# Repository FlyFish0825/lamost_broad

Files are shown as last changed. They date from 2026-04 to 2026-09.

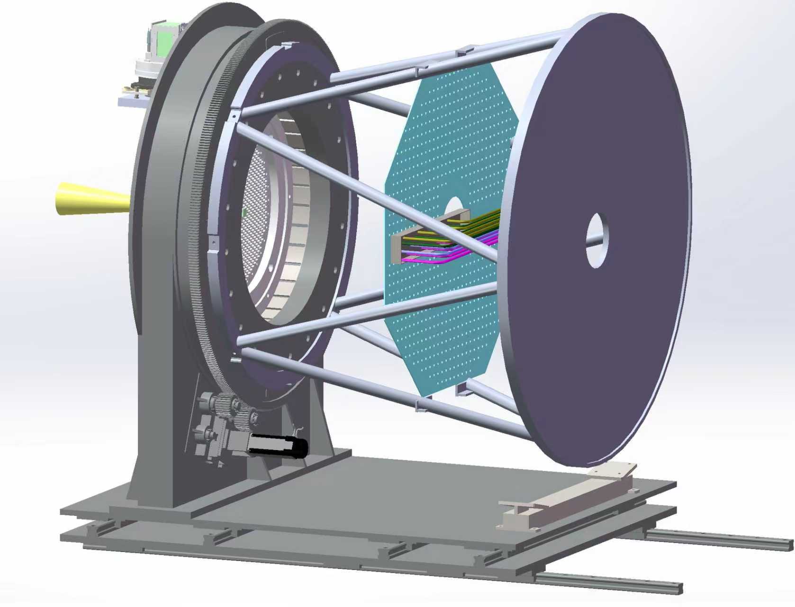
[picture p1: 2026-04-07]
just外接板/picture/微信图片_20260402115243_79_106.jpg

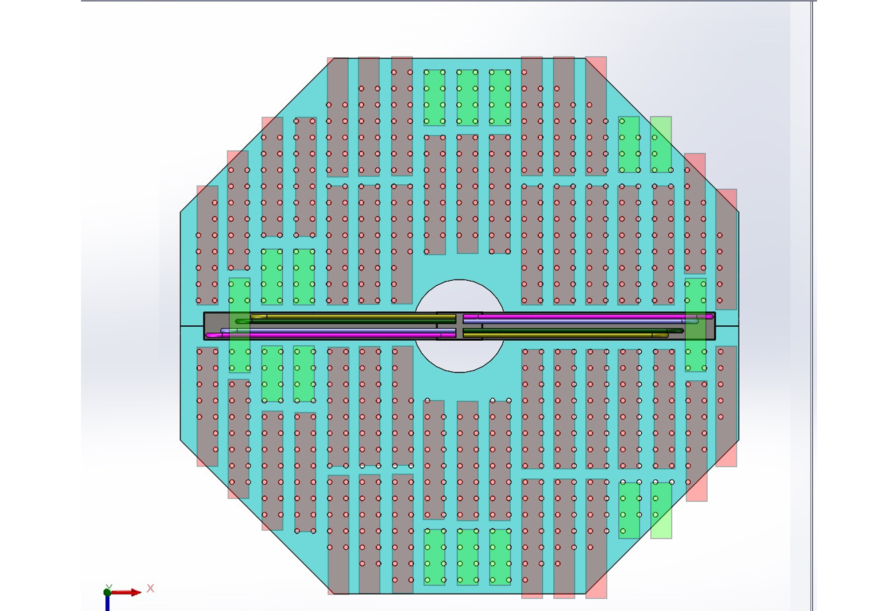
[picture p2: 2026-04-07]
just外接板/picture/示意图4.jpg

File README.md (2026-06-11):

# LAMOST 外接板（Broad Board）

LAMOST（Large Sky Area Multi-Object Fiber Spectroscopic Telescope）光谱巡天望远镜外接板项目。本项目包含一块约 **1.3 米**的大尺寸基板（机械背板），以及安装在其上的 **56 块小单元 PCB**。每块小单元 PCB 搭载一片 STM32F302 MCU，各 PCB 之间通过基板上的 CAN 总线互联通信，用于光纤光谱仪的信号中继与分配。

## 项目概览

| 类别 | 说明 |
|---|---|
| **主控芯片** | STM32F302x8（Cortex-M4, 72MHz），每块小单元 PCB 一片 |
| **通信方式** | CAN 2.0, 250kbps，CAN 总线绘制在基板上，56 节点多主网络 |
| **晶振** | 24MHz 外部晶振 |
| **基板尺寸** | ≈1.3m，中间方形倒角，走线孔直径 50mm，中间孔 150mm |
| **小单元 PCB** | 共 56 块，每块搭载 STM32F302 + CAN 收发器，16 通道输出 |
| **PCB 层数** | 2 层板（小单元 PCB） |
| **设计工具** | 立创EDA / EasyEDA (PCB), SolidWorks (3D 结构) |
| **开发周期** | 2026.03 — 至今 |
| **作者** | dushiyu ([FlyFish0825](https://github.com/FlyFish0825)) |

## 系统架构

```
┌──────────────────────────────────────────────────────────────────┐
│                      基板（外接板基板）≈1.3m                        │
│                                                                  │
│   ┌──────────┐  ┌──────────┐  ┌──────────┐       ┌──────────┐   │
│   │  PCB #1  │  │  PCB #2  │  │  PCB #3  │  ...  │  PCB #56 │   │
│   │ STM32F302│  │ STM32F302│  │ STM32F302│       │ STM32F302│   │
│   │ CAN收发器│  │ CAN收发器│  │ CAN收发器│       │ CAN收发器│   │
│   │ 16通道   │  │ 16通道   │  │ 16通道   │       │ 16通道   │   │
│   └────┬─────┘  └────┬─────┘  └────┬─────┘       └────┬─────┘   │
│        └──────────────┴─────────────┴── CAN 总线 ────┘          │
│                         基板上走线                                │
│   ┌──────────────────────────────────────────────────────────┐   │
│   │                    电源总线（基板上走线）                    │   │
│   └──────────────────────────────────────────────────────────┘   │
│                                                                  │
│   走线孔 Φ50mm × N         中心孔 Φ150mm                         │
└──────────────────────────────────────────────────────────────────┘
```

- **基板（外接板基板）**：大型机械背板，上面绘制 CAN 总线和电源线，开有走线孔和中心孔，56 块小单元 PCB 安装固定其上
- **小单元 PCB**：共 56 块，每块搭载一片 STM32F302 MCU 和 CAN 收发器，16 通道输出。各 PCB 通过基板上的 CAN 总线互联，形成 56 节点多主 CAN 网络。其中一块作为主节点（主节点布局已调整优化）
- **CAN 总线**：在基板上走线，连接所有 56 块 PCB，总线两端含开关控制的 120Ω 终端电阻

## 目录结构

```
lamost_broad/
├── Canvas/                           # PCB 接口映射可视化工具
│   ├── canvas.html                   # HTML Canvas 交互式编辑器（707行）
│   ├── pcb_c_array.txt               # 52块PCB的C数组映射数据（待更新至56块）
│   └── pcb_mapping_*.json            # 接口映射关系 JSON 数据
│
├── just外接板/                        # 基板及 PCB SolidWorks 3D 模型、汇报资源
│   ├── picture/                      # 示意图、实物照片、PSD 设计稿
│   │   ├── 主节点布局.png/psd        # 主节点布局图
│   │   ├── 正视图.png / 正视图布线.psd # 基板正视图及布线图
│   │   ├── 示意图.jpg / 示意图2/4.jpg # 多种视角示意图
│   │   ├── 示意图横置.jpg            # 横置示意图
│   │   ├── 数目.png                  # PCB 数量统计图
│   │   ├── 对照.psd                  # 对照设计稿
│   │   └── QQ*/微信图片_*.jpg        # 实物及参考照片
│   ├── ppt/                          # 阶段性汇报 PPT（5个版本）
│   │   ├── 0402.pptx                 # 4月2日汇报
│   │   ├── 0409.pptx                 # 4月9日汇报
│   │   ├── 0413.pptx                 # 4月13日汇报
│   │   ├── 0423.pptx                 # 4月23日汇报
│   │   └── 0429.pptx                 # 4月29日汇报
│   ├── 外接板基板.SLDPRT / .STEP     # 基板（大型机械背板）3D 模型
│   ├── 基板1.SLDPRT / 基板2.SLDPRT / .STL  # 基板各版本
│   ├── 分块插线板_16.STEP            # 16通道分块插线板（小单元PCB模型）
│   ├── 分块插线板_16接头间距加大.STEP # 加大接头间距版本
│   ├── 外接板.SLDPRT / 外接板pcb.SLDPRT # 外接板及PCB装配
│   ├── 布线.SLDPRT / .STL            # 基板上的布线 3D 模型
│   ├── 接口.step / 接口示意/         # 接口模型及示意工程
│   └── 示意图.psd                    # 总体示意图设计稿
│
├── lamost_broad_MCU/                 # STM32F302 嵌入式固件工程（烧录至每块小单元 PCB）
│   ├── Core/
│   │   ├── Inc/                      # 头文件（can.h, gpio.h, tim.h, usart.h, main.h 等）
│   │   ├── Src/                      # 源文件（main.c, can.c, tim.c, gpio.c, dma.c 等）
│   │   └── pcb_broad/                # PCB 端口映射数组（just_led.c/h）
│   ├── Drivers/                      # STM32 HAL 库驱动
│   ├── CMakeLists.txt                # CMake 构建配置
│   ├── CMakePresets.json             # CMake 预设
│   ├── lamost_broad_MCU.ioc          # STM32CubeMX 配置文件
│   ├── startup_stm32f302x8.s         # 启动汇编文件
│   ├── STM32F302XX_FLASH.ld          # 链接脚本
│   └── build/                        # 构建输出
│
├── pcb_3d_model/                     # PCB 3D 装配模型
│   ├── 3D_PCB2_2026-04-02.SLDASM     # SolidWorks 装配体
│   └── 3D_PCB2_2026-04-02.step       # STEP 通用格式
│
├── 外接板20260402.eprj               # 最新版基板工程文件（立创EDA）
├── 外接板20260112_DXF/               # 基板 DXF 机械图 / PDF 导出
│   ├── DXF_PCB2_2026-01-12_AutoCAD2007.dxf
│   └── PCB_PCB2_2026-01-12.pdf
├── 小单元原理图设计+PCB.zip           # 小单元 PCB 参考设计（原理图+PCB+说明文档）
├── 外接板20260*.eprj                 # 各历史版本基板工程文件
├── 外接板*_backup/                   # 各版本自动备份归档
├── debug.log                         # 调试日志
└── README.md                         # 本文件
```

## 硬件架构详解

### 基板（外接板基板）—— 机械背板

基板是一块约 **1.3 米**的大型机械背板，用于承载 56 块小单元 PCB 并提供互联走线：

- **尺寸**：约 1.3m，中间为方形倒角设计
- **材质**：金属/绝缘基材
- **走线孔**：多个直径 Φ50mm 的走线孔，用于线缆穿绕
- **中心孔**：中间开 Φ150mm 大直径孔
- **对位孔**：含中心对位圆柱孔，用于 PCB 安装定位
- **挖空区域**：特定区域镂空/挖空处理
- **基板布线**：基板上绘制 CAN 总线（统一在右侧走线）和电源总线，连接各 PCB
- **电源接口**：电源接口位于基板背面

基板 3D 模型文件：
- `just外接板/外接板基板.SLDPRT` / `外接板基板.STEP` — SolidWorks 零件及通用格式
- `just外接板/基板2.STL` — 3D 打印格式（约 31MB）
- `just外接板/布线.SLDPRT` / `布线.STL` — 基板布线模型（约 19MB）

### 小单元 PCB —— 56 块（搭载 STM32）

每块小单元 PCB 是一款独立的两层电路板，搭载完整的 MCU 系统，安装在基板之上：

| 参数 | 说明 |
|---|---|
| **数量** | 共 56 块 |
| **MCU** | STM32F302x8（Cortex-M4, 72MHz），每块一片 |
| **通道数** | 每块 16 个通道/端口 |
| **总端口** | 56 × 16 = 896 个 |
| **层数** | 2 层板 |
| **晶振** | 24MHz 外部晶振 |
| **CAN 收发器** | 外接 CAN 收发芯片，接入基板上的 CAN 总线 |
| **电源方案** | 5V → 3.3V，功率电感降压，钽电容滤波 |
| **终端电阻** | 120Ω CAN 终端匹配电阻，开关控制（位于总线两端节点） |
| **LED 指示** | PWM 控制 LED（10% 占空比起步） |
| **调试接口** | SWD 调试/下载接口 |
| **复位** | Boot0 复位电路 |
| **网络拓扑** | 56 节点多主 CAN 网络，其中一块为主节点 |

> 所有 56 块 PCB 运行同一份固件（`lamost_broad_MCU/`），通过 CAN 总线协议中的节点 ID 区分角色。主节点负责协调调度，各从节点响应指令。

小单元 PCB 参考设计（`小单元原理图设计+PCB.zip`）包含：
- 原理图（PDF）
- PCB 布局图（PDF + 仿真顶层/底层图）
- SMT 3D 渲染图（含标注）
- 实物照片（顶层/底层）
- 主体尺寸图
- 设计说明文档（docx）

### 分块插线板

用于连接各小单元 PCB 的接口模块（16 通道），3D 模型文件：
- `分块插线板_16.STEP` — 标准间距版本
- `分块插线板_16接头间距加大.STEP` — 加大接头间距版本

## 固件功能

固件工程 `lamost_broad_MCU/` 基于 STM32CubeMX + HAL 库，使用 CMake 构建，烧录至每一块小单元 PCB 上运行。

### 主要功能模块

| 模块 | 说明 |
|---|---|
| **CAN 通信** | FIFO0 中断收发，250kbps，Filter 全部接收模式，56 节点多主网络 |
| **LED 控制** | PWM 调光（10% 占空比起步），`just_led.c/h` 实现 |
| **DMA** | 数据搬移，用于 CAN 数据高效传输 |
| **UART** | printf 重定向，调试打印输出 |
| **TIM** | 定时器用于 PWM 生成和时序控制 |
| **GPIO** | 通用 IO 控制，CAN 引脚复用配置 |
| **中断** | CAN FIFO0 中断接收，接收值存储与处理 |
| **端口映射** | `pcb_1_map[16]` 等数组定义基板孔位到 PCB 端口的映射关系 |

### 关键引脚映射

| 功能 | 引脚 | 说明 |
|---|---|---|
| CAN TX | PA12 | GPIO_AF9_CAN 复用 |
| CAN RX | PA11 | GPIO_AF9_CAN 复用 |
| CAN_S | PB0 | CAN 收发器模式控制 |
| LED | PB1 | PWM 控制输出 |

### CAN 总线参数

- **波特率**：250 kbps
- **主频**：72MHz（24MHz 晶振 × PLL）
- **终端电阻**：120Ω，总线两端节点含开关控制（可切换），带丝印标注
- **CAN 接口**：CANH / CANL 配对（丝印方向已修正）
- **拓扑**：基板上绘制的线性总线，56 节点并联
- **Filter**：当前配置为全部接收（不过滤）

## 接口映射可视化工具

[Canvas/canvas.html](Canvas/canvas.html) 是一个基于 HTML5 Canvas 的交互式编辑器，用于可视化编辑基板孔位与小单元 PCB 端口之间的连接映射关系。

### 功能特性
- **双侧画布**：左侧显示基板阵列，右侧显示 PCB 端口阵列
- **双向连线**：点击左侧孔位 + 右侧端口即可建立映射关系
- **智能编号**：自动编号，支持拖拽连线
- **缩放平移**：双侧支持滚轮缩放与拖拽平移
- **导出功能**：
  - 导出 JSON 格式配置（`pcb_mapping_*.json`）
  - 导出 C 语言数组代码（`pcb_c_array.txt`），格式为 `pcb_N_map[16]`，可直接用于固件编译
- **当前状态**：52 块 PCB 已配置（`pcb_1_map` ~ `pcb_52_map`，每块 16 端口，共 832 端口），待更新至 56 块

### 使用方法
直接用浏览器打开 `Canvas/canvas.html`，可用 `📂 加载配置 JSON` 加载已有的映射关系文件。

## 3D 模型索引

### 基板相关
| 文件 | 格式 | 大小 | 说明 |
|---|---|---|---|
| `just外接板/外接板基板.STEP` | STEP | ~567KB | 基板通用 3D 格式 |
| `just外接板/基板2.STL` | STL | ~30MB | 基板 3D 打印格式 |
| `just外接板/基板2.SLDPRT` | SLDPRT | ~4MB | SolidWorks 基板零件 |
| `just外接板/布线.STL` | STL | ~19MB | 基板布线 3D 模型 |

### PCB 相关
| 文件 | 格式 | 大小 | 说明 |
|---|---|---|---|
| `pcb_3d_model/3D_PCB2_2026-04-02.step` | STEP | ~6.5MB | PCB 完整 3D 装配 |
| `just外接板/分块插线板_16.STEP` | STEP | ~757KB | 16通道分块插线板 |
| `just外接板/外接板pcb.SLDPRT` | SLDPRT | ~52KB | PCB SolidWorks 模型 |

## 开发历程

| 时间 | 主要进展 |
|---|---|
| 2026-03-17 | 项目初始化，添加 SolidWorks 模型和基础文件 |
| 2026-04-02 | 3D PCB 模型创建，安装孔位设计，16+4×2 布局初步确定 |
| 2026-04-03 | 重新调整布线，CAN 统一放在右侧，电源和 CAN 接口改到背面 |
| 2026-04-07 | 添加 SolidWorks 零件图、布线设计、首批汇报 PPT |
| 2026-04-09 | 外接板零件图、布线优化 |
| 2026-04-13 | 过孔 GND 调试、导电过孔、走线空间图、阶段性汇报 |
| 2026-04-22~23 | 小单元 PCB 初定稿、STM32 原理图设计、PPT 汇报 |
| 2026-04-27 | 基板尺寸缩小至 1.3m，中间改为方形倒角，布线调整为真实比例 |
| 2026-04-28 | 添加小单元原理图参考设计、STL 通用 3D 文件、HTML 可视化工具 |
| 2026-04-30 | 外接板布局对应 PCB 初步前端代码 |
| 2026-05-03 | Canvas 可视化编辑器完善，基板添加中心对位圆柱孔 |
| 2026-05-07 | STM32 固件开发：GPIO CAN 复用、调试下载、功率电感电源方案 |
| 2026-05-09 | LED 驱动代码、PWM 调光、时钟配置 72MHz、两层板打板测试 |
| 2026-05-14 | CAN 通信调试（FIFO0、中断、Filter、250kbps）、钽电容、CANH/CANL 丝印修正 |
| 2026-05-25 | 主节点（56块中其中一块）布局调整 |
| 2026-06-03 | 基板 CAN 布线、电源布线、末端电阻、Boot0 复位电路 |
| 2026-06-10~11 | 走线孔 Φ50mm/Φ150mm、CAN 总线绘制、末端电阻开关控制及丝印 |

## 快速开始

### 固件编译与烧录

```bash
cd lamost_broad_MCU
cmake --preset Debug
cmake --build build/Debug
# 使用 ST-Link / J-Link 逐块烧录至 56 块小单元 PCB
```

或使用 STM32CubeMX 打开 `lamost_broad_MCU.ioc` 进行配置和代码生成。

### 查看基板设计

使用立创EDA 或 EasyEDA 打开 `外接板20260402.eprj` 工程文件。

### 查看 3D 模型

- **SolidWorks**：打开 `just外接板/` 中的 `.SLDPRT` 文件或 `pcb_3d_model/3D_PCB2_2026-04-02.SLDASM` 装配体
- **通用查看器**：任意 STEP/STL 查看器可打开 `.step` / `.stl` 文件

### 接口映射编辑器

直接用浏览器打开 `Canvas/canvas.html`。

## 相关资源

- **汇报 PPT**：[just外接板/ppt/](just外接板/ppt/) — 共 5 个阶段性汇报文件（0402 ~ 0429）
- **实物及示意图**：[just外接板/picture/](just外接板/picture/) — 包含照片、示意图、PSD 设计稿
- **DXF 机械图**：[外接板20260112_DXF/](外接板20260112_DXF/) — AutoCAD DXF 和 PDF 格式
- **小单元参考设计**：`小单元原理图设计+PCB.zip` — 原理图、PCB、BOM、实物图、设计说明

## License

待定

---

*最后更新：2026-06-11，基于 git 提交历史及项目文件结构整理。*

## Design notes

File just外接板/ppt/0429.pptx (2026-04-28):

## 外接板

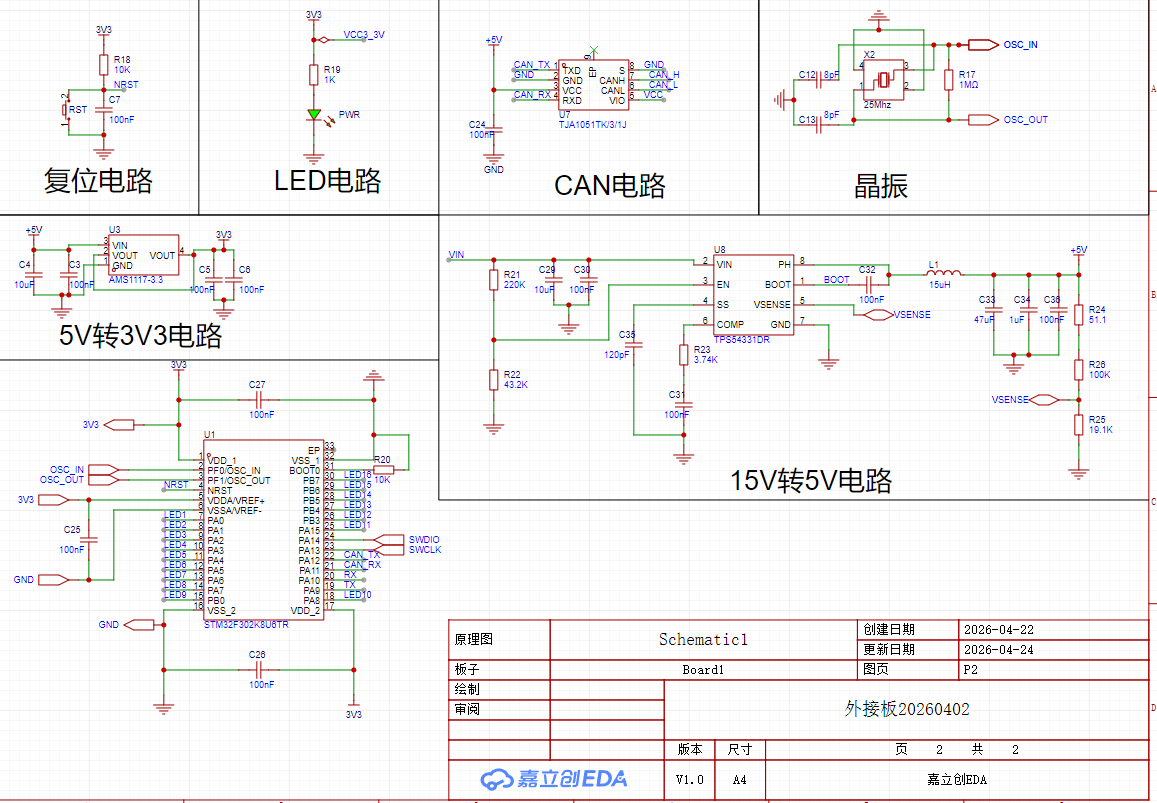
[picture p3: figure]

## 外接板

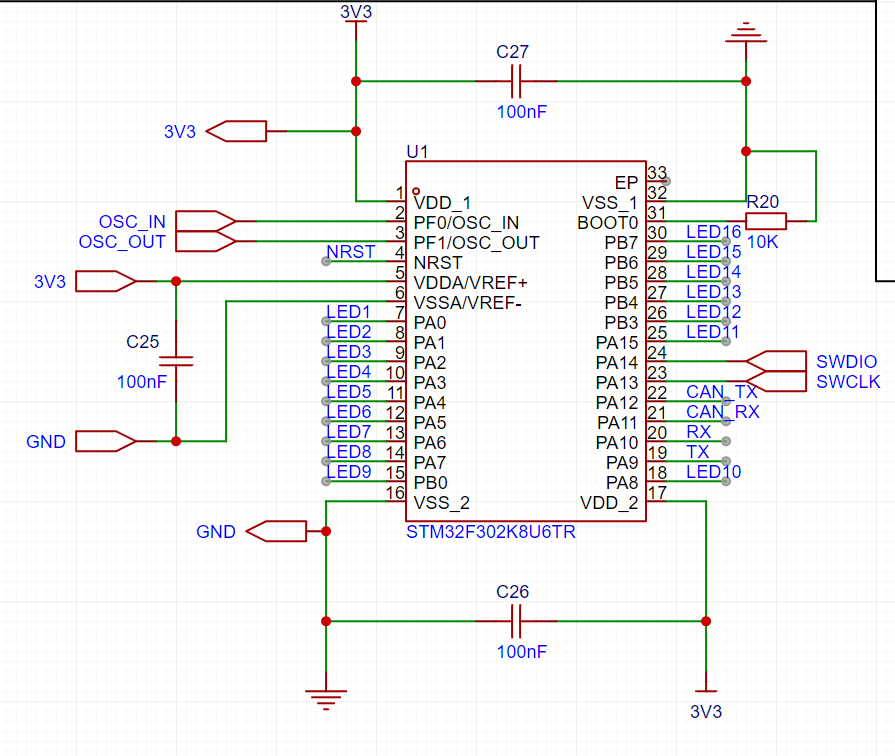
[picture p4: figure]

每个引脚对应一个LED，正好用完

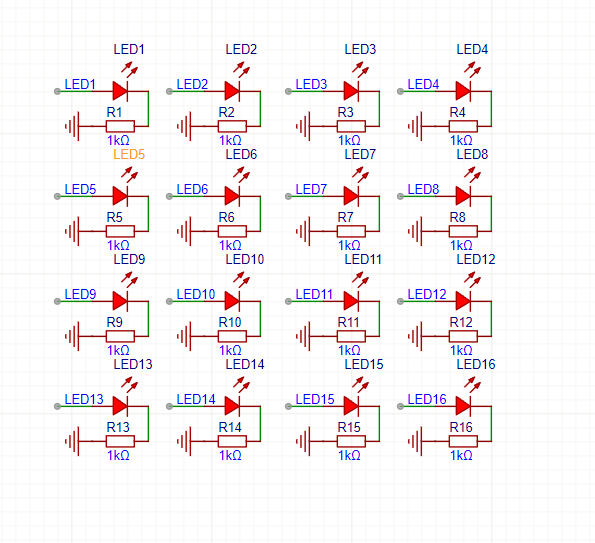
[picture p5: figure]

## 外接板

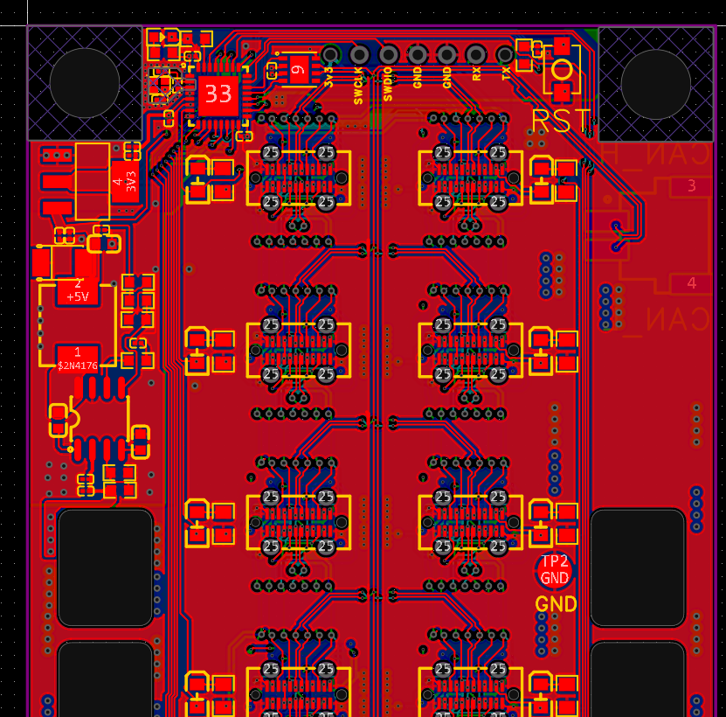
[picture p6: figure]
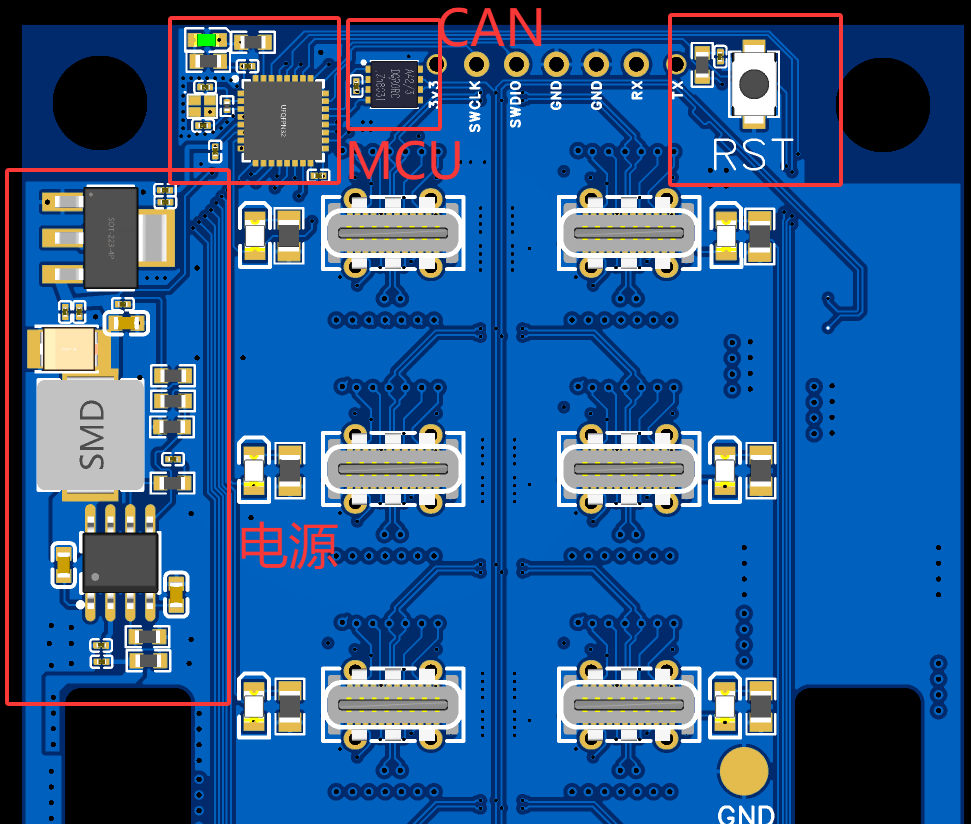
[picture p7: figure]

## 外接板

LED的分布式2*8的共16个阵列分布
使用MCU监听LED的电压变化，同时监听CAN通讯线上的消息内容。当收到点亮LED的指令后，记录此时CAN通讯线上的呼叫ID号，同时记录对应电平发生变换的LED位置。
ID------位置 相互关联
然后给定板载MCU持续给定电平，保持LED常亮。
当多个单元需要更换时。根据MCU已经记录的
ID------位置 的相互关系，通过上位机发送指定ID单元安装的指令或者LED闪烁的指令，板载MCU通过记录的ID---位置关系，点亮或者让对应的LED闪烁。

## 外接板

graph TD
A([系统上电/复位]) --> B[硬件初始化<br>CAN / GPIO / 定时器]
B --> C[清空/加载 模块数据库]
C --> D{等待事件发生}
D -- CAN接收中断标志 --> E[进入CAN处理逻辑]
E --> F[解析CAN ID和数据]
F --> G{数据库中是否存在该ID?，且指令类别是0x66--LED相关}
G -- 否 --> H[记录新ID / 暂存待绑定,等待最近的GIPO中断关联对应引脚]
H -->R[把引脚和CAN_ID添加到数据库，同时给一个弱上拉高电平]
R -->D
G -- 是 --> I{指令是否为闪烁}
I --是 --> J{LED闪烁}
J -->D
I --否 --> D
D-->O{扫描LED，记录状态是闪烁，实际状态是否是闪烁}
O -- 否 -->O1[单元已插入，GPIO改为输入模式]
O1 -->D
O -- 是 -->O

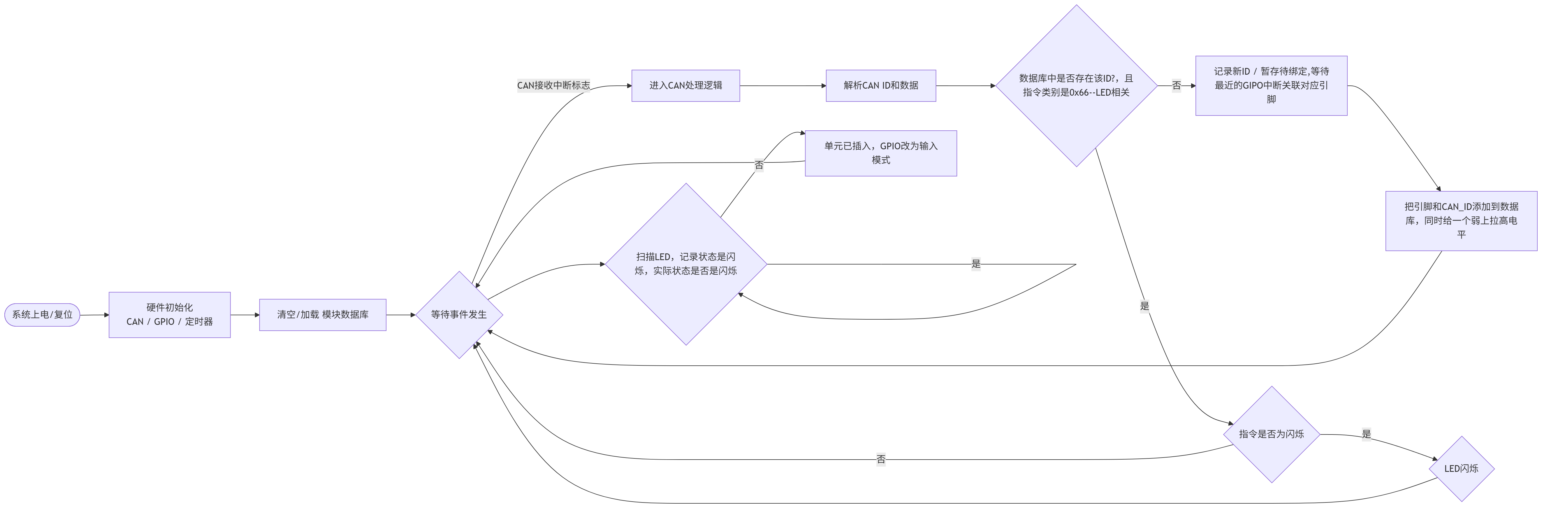
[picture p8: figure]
mermaid-diagram-2026-04-27-114738

## 外接板

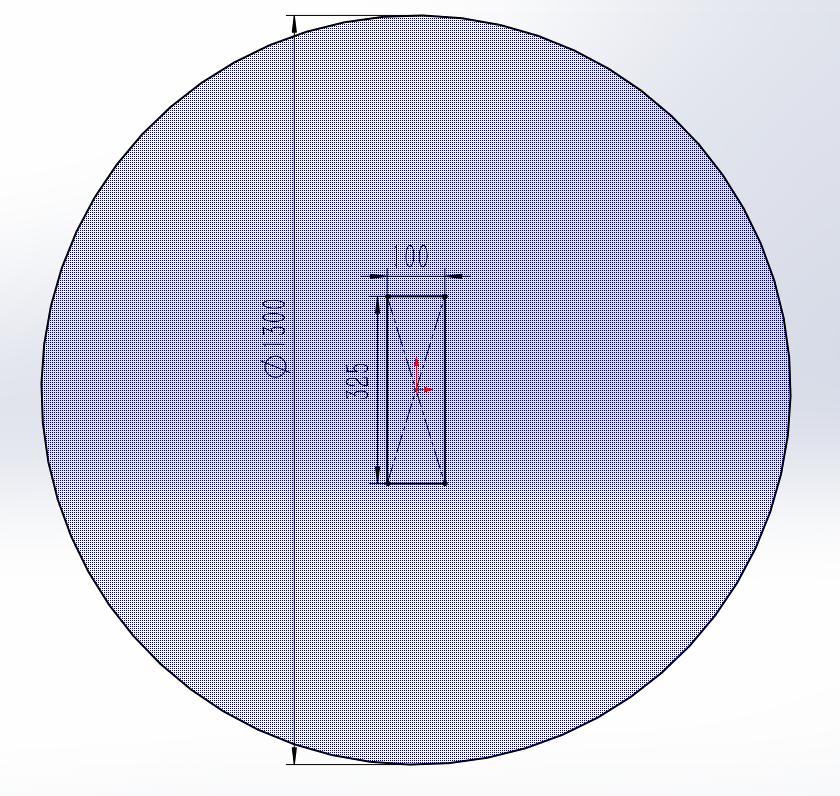
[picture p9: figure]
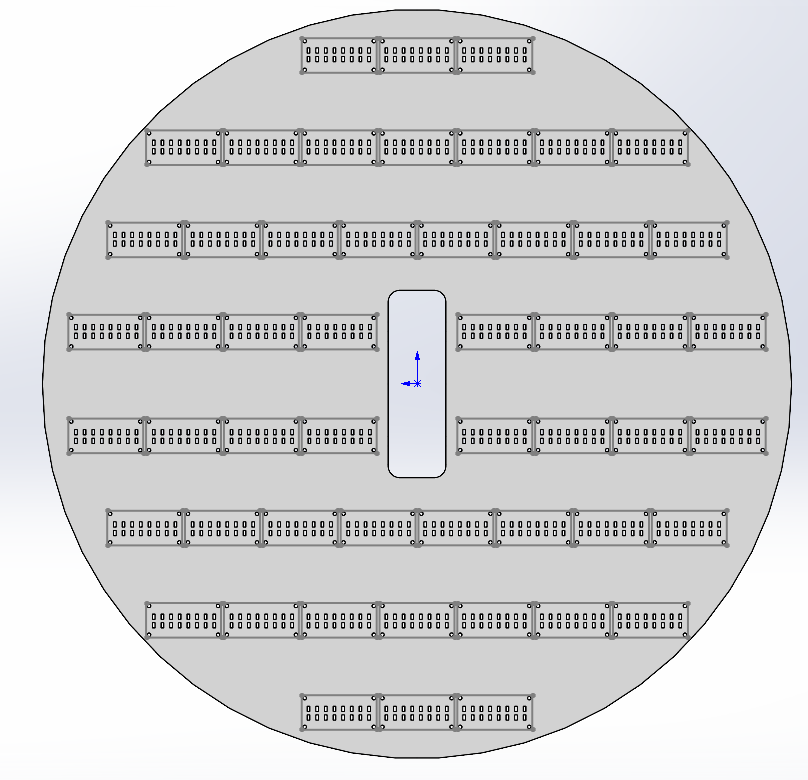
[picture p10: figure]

## 外接板

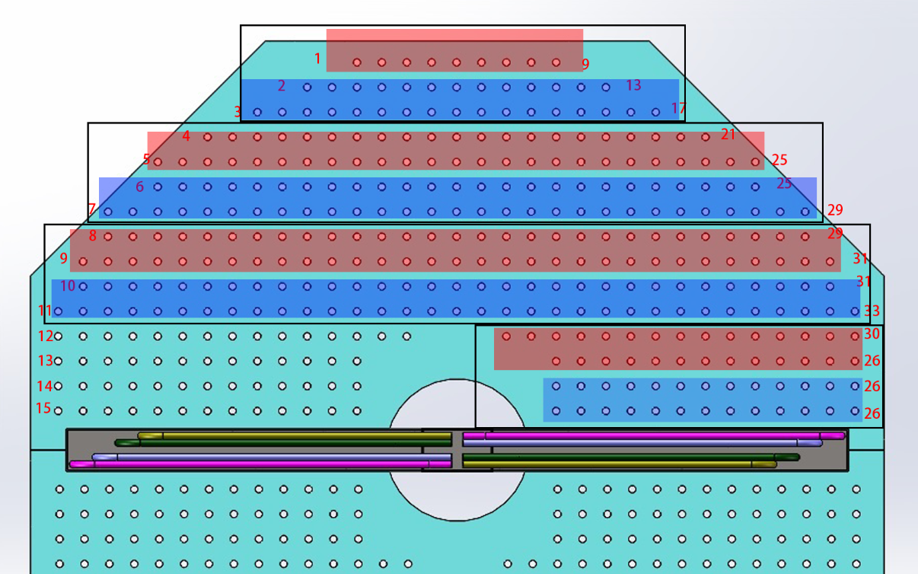
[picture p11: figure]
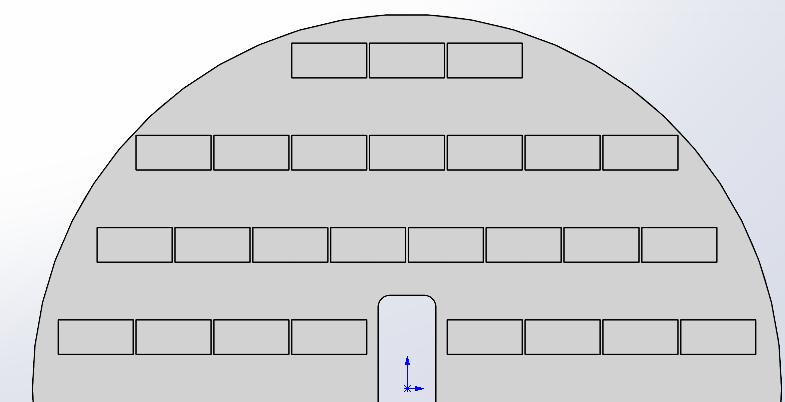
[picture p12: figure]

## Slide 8

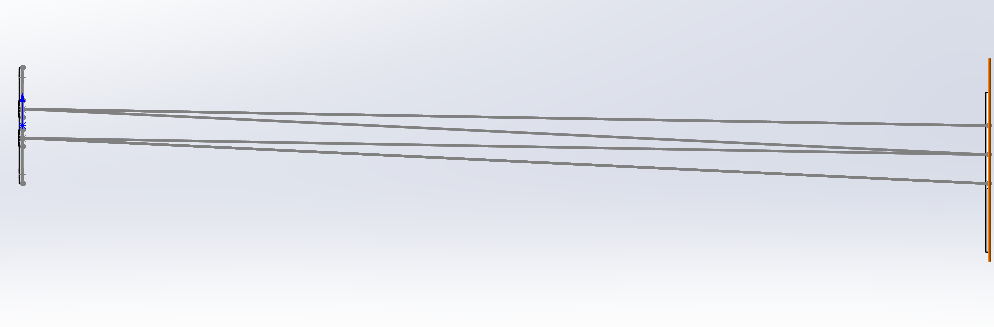
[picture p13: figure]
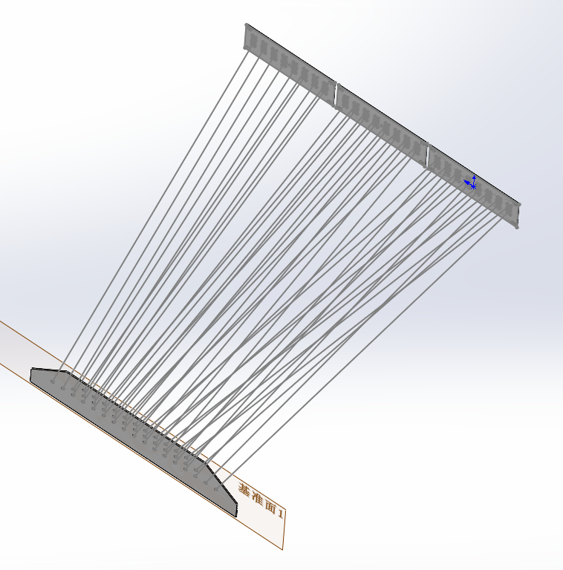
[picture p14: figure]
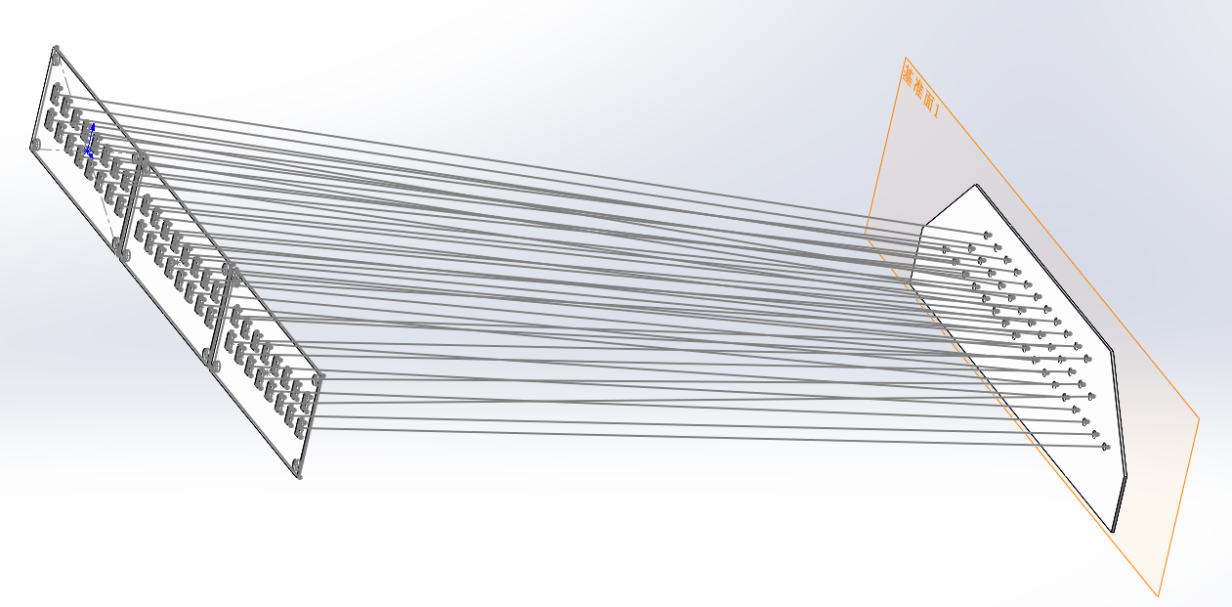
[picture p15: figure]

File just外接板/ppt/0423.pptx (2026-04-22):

## 外接板

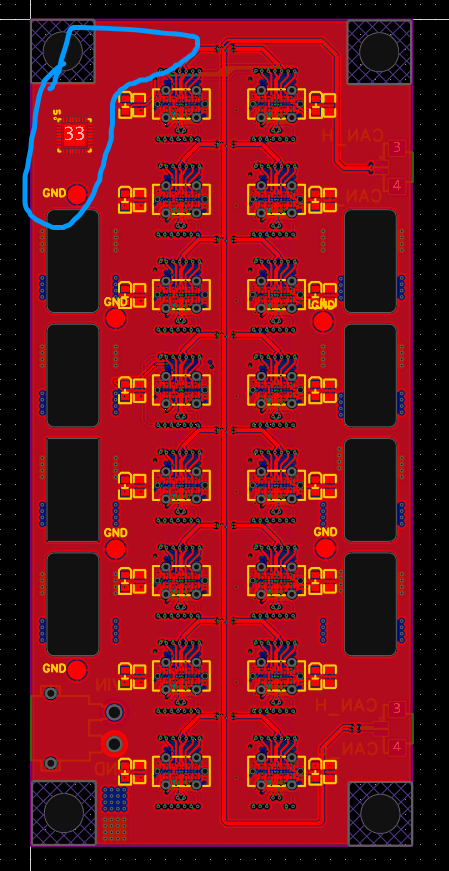
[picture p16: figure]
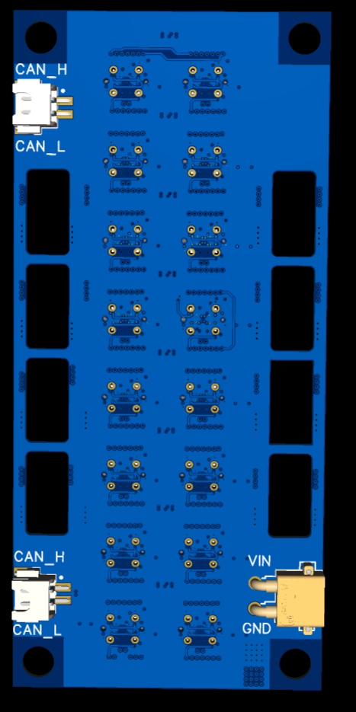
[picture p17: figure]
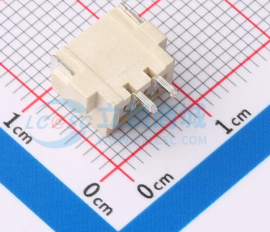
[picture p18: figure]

更换了接口
LED位置移动到两测
蓝线位置预留mcu电路部分

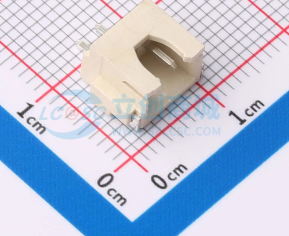
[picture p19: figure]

ZX-XH2.54-2PWT

## 外接板

LED的分布式2*8的共16个阵列分布
使用MCU监听LED的电压变化，同时监听CAN通讯线上的消息内容。当收到点亮LED的指令后，记录此时CAN通讯线上的呼叫ID号，同时记录对应电平发生变换的LED位置。
ID------位置 相互关联
然后给定板载MCU持续给定电平，保持LED常亮。
当多个单元需要更换时。根据MCU已经记录的
ID------位置 的相互关系，通过上位机发送指定ID单元安装的指令或者LED闪烁的指令，板载MCU通过记录的ID---位置关系，点亮或者让对应的LED闪烁。

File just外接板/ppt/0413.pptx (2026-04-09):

## 外接板

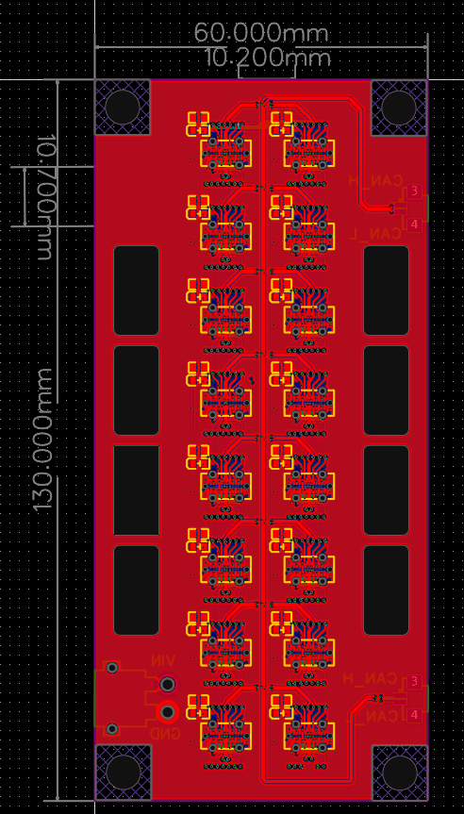
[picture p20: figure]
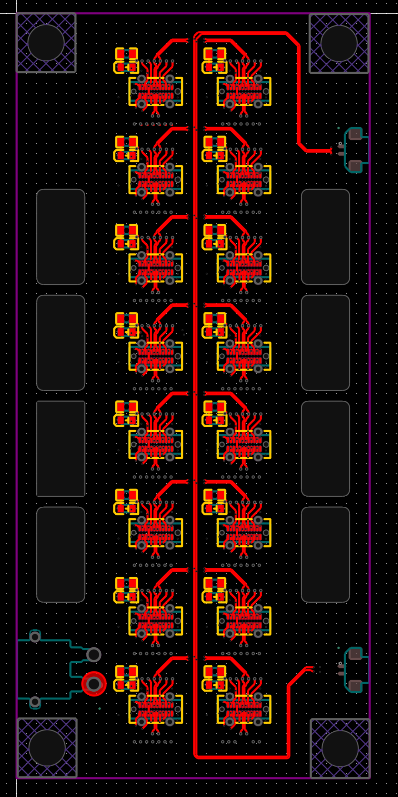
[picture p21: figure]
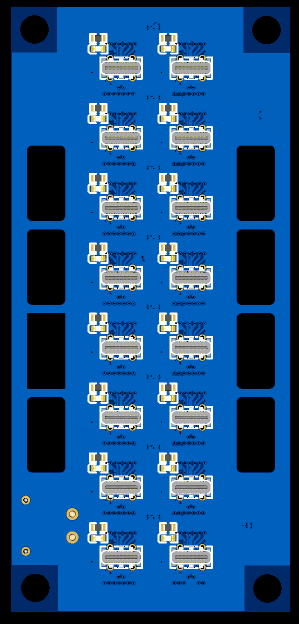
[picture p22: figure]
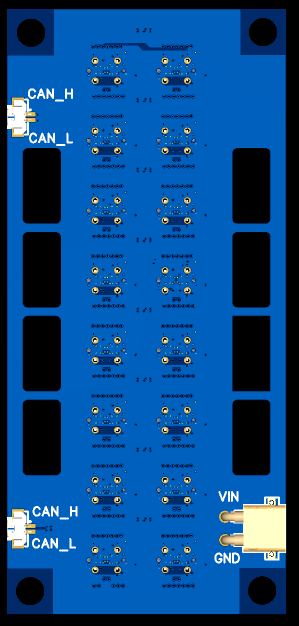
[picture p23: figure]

## 外接板

微信图片_20260402115243_79_106
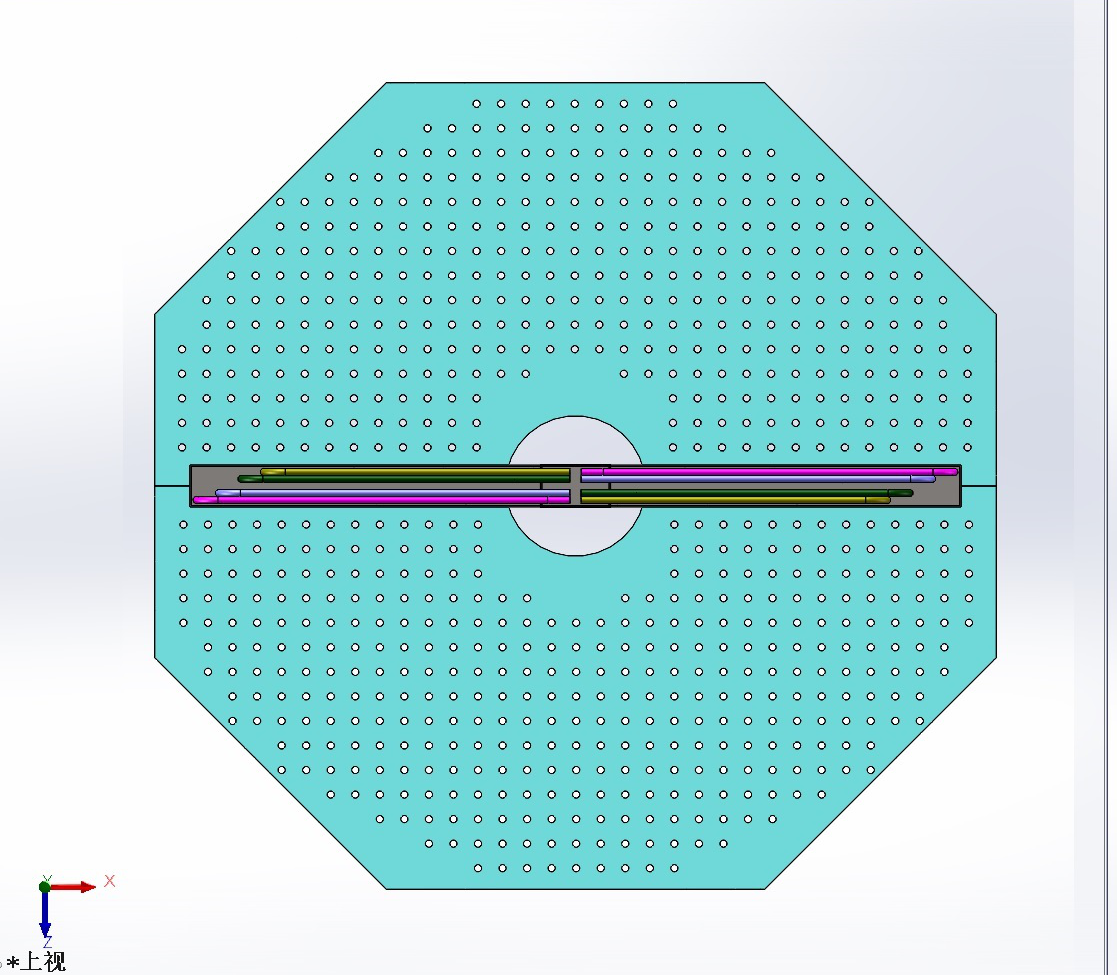
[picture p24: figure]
微信图片_20260402115243_80_106

## 外接板

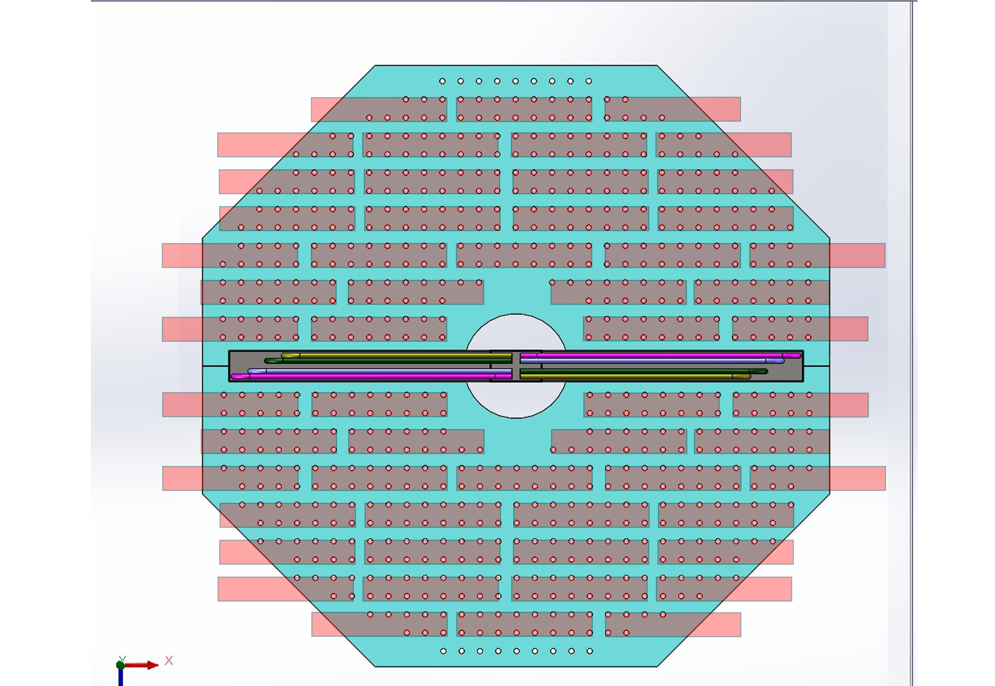
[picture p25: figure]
示意图横置
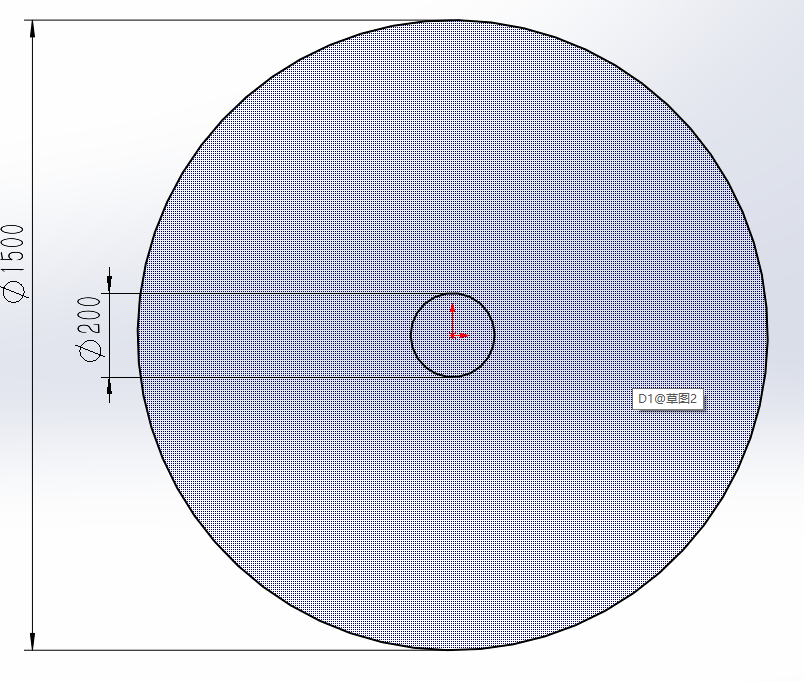
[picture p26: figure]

## 外接板


## 外接板

电源线


信号线


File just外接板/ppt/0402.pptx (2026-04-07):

## 外接板


板子的typec接口间距扩大了两倍现在是25mm。板子的大小适合扩大了一部分。宽度是80mm，长度是220mm。其他功能保持不变

## 外接板

微信图片_20260402115243_79_106
微信图片_20260402115243_80_106

## 外接板

示意图
示意图2

## 外接板


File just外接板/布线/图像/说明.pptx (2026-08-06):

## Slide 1


整体结构图
长方形为外接板
正方形为主节点

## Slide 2


基板

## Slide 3


电源布线

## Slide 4


can通信线

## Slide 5

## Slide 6

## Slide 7

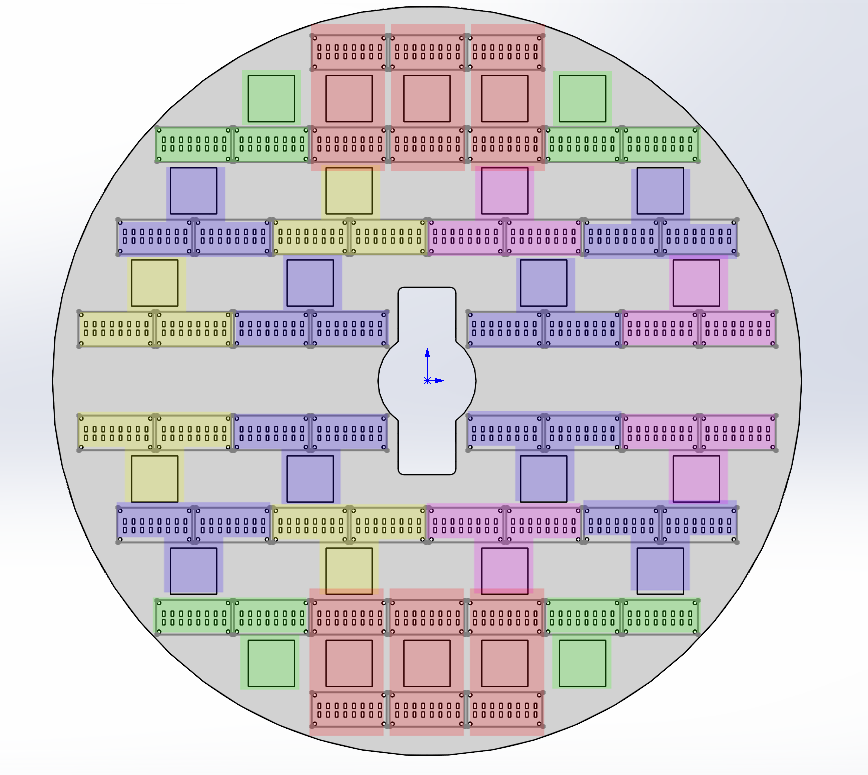
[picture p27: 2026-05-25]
just外接板/picture/主节点布局.png

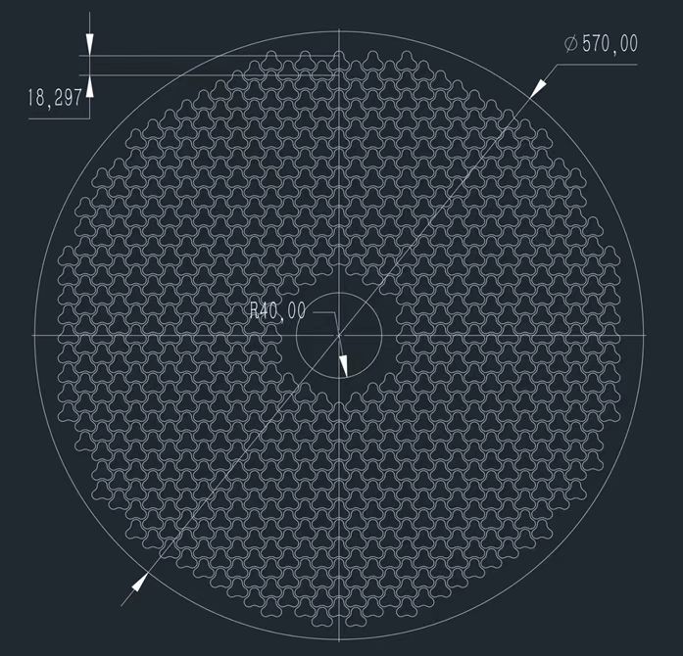
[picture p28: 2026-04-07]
just外接板/picture/微信图片_20260402115240_77_106.jpg

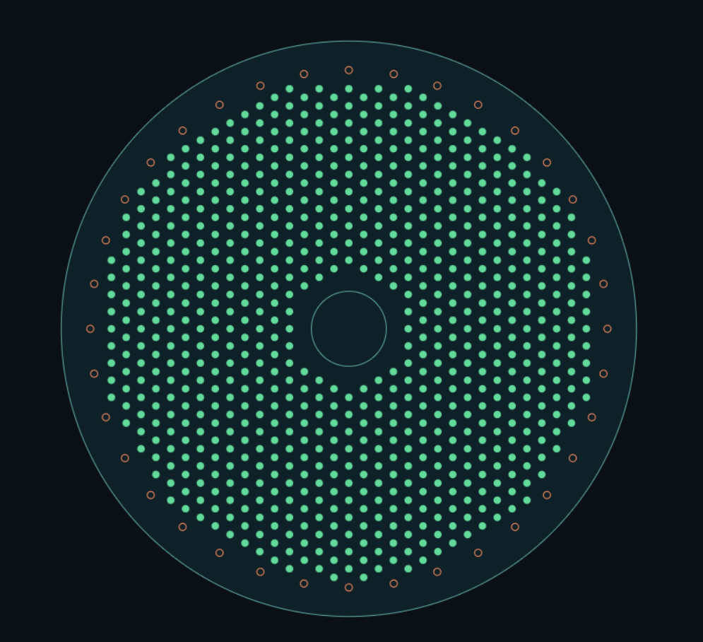
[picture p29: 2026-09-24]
just外接板/picture/焦面.png

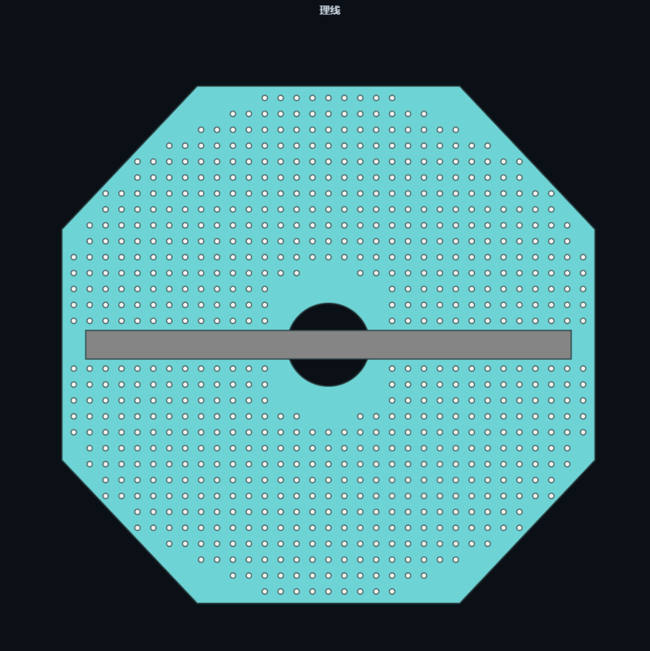
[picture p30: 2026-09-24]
just外接板/picture/理线层.png

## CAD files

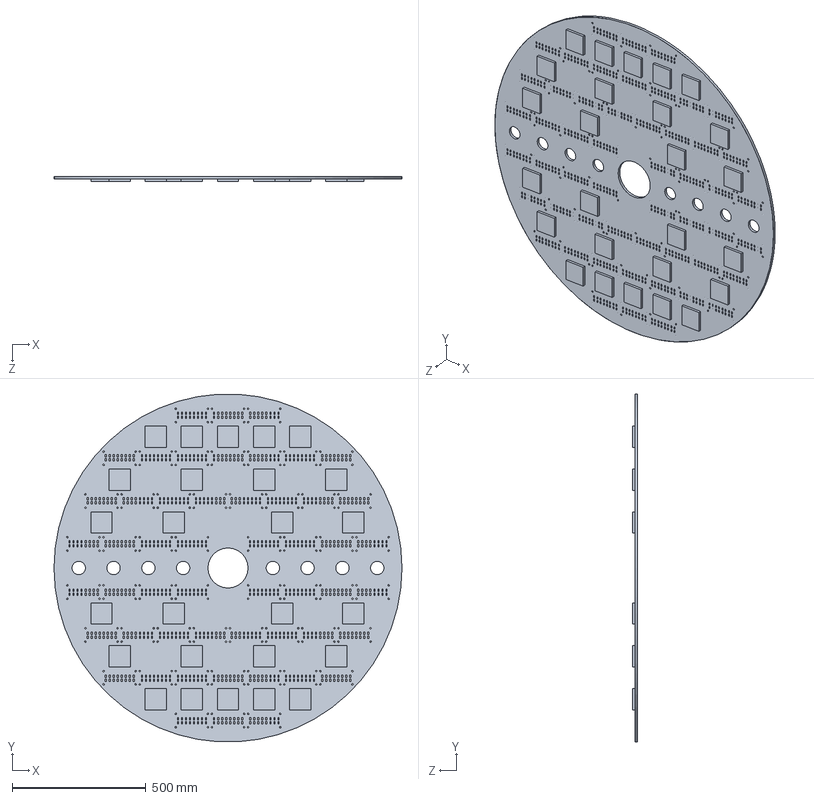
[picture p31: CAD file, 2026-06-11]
just外接板/基板2.SLDPRT
1300.0 x 1300.0 x 20.0 mm

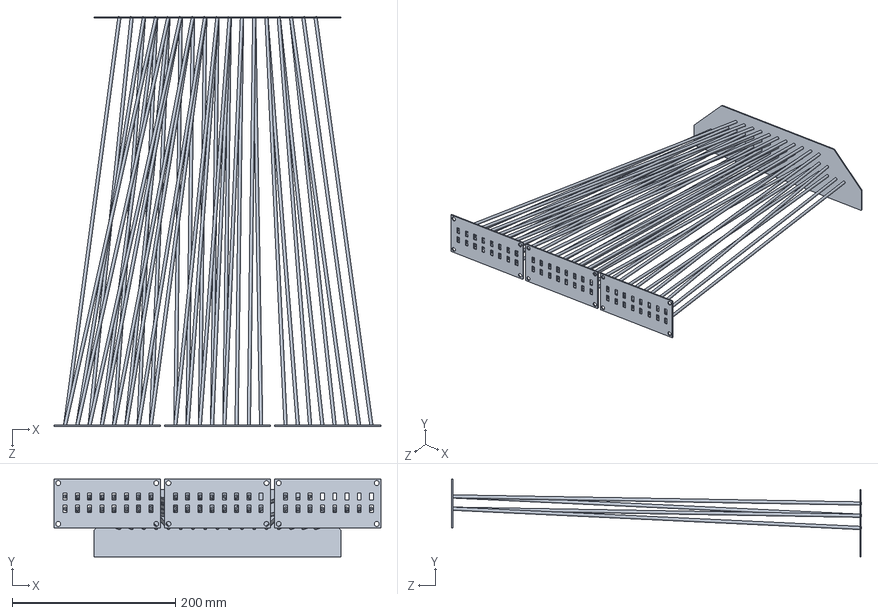
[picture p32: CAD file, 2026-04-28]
just外接板/布线.SLDPRT
400.0 x 95.5 x 502.0 mm

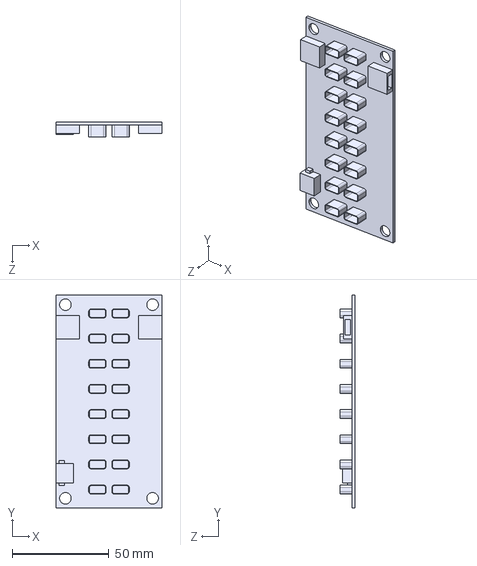
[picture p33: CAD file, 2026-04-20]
just外接板/分块插线板_16.STEP
55.0 x 110.0 x 8.00 mm

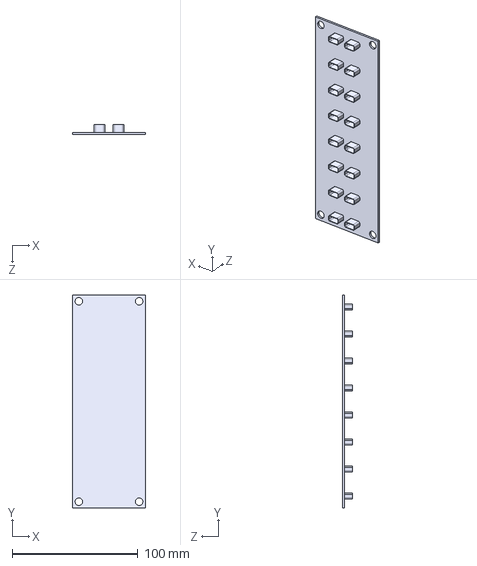
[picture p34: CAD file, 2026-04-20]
just外接板/分块插线板_16接头间距加大.STEP
57.9 x 169.5 x 8.00 mm

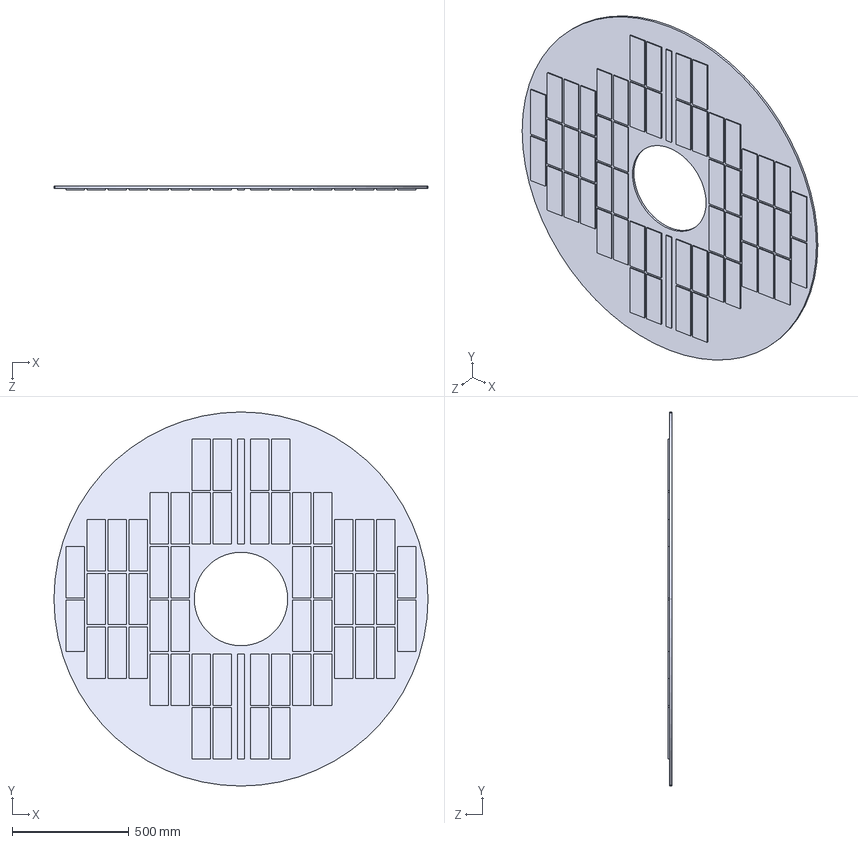
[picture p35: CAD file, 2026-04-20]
just外接板/外接板基板.STEP
1600.0 x 1600.0 x 15.0 mm

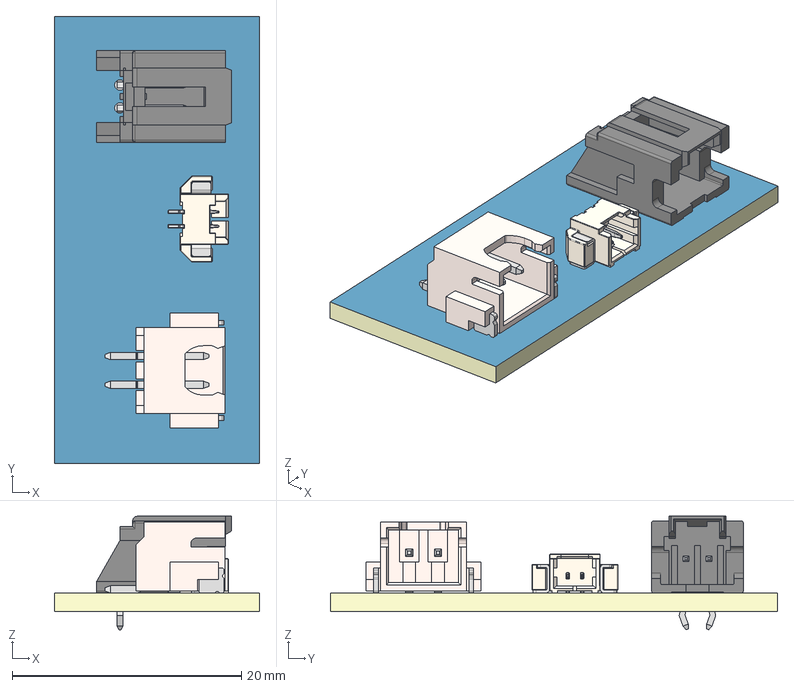
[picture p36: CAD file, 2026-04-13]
just外接板/接口.step
17.9 x 39.0 x 9.90 mm
Board~9u25
TopCopper~9u25
BottomCopper~9u25
TopFpcStiffener~9u25
BottomFpcStiffener~9u25
CONN-SMD_2P-P2.54_MEGASTAR_ZX-XH2.54-2PWT~CONN-SMD_2P-P2.54_MEGASTAR_ ZX-XH2.54-2PWT~9u25
CONN-TH_2P-55935-0210~CONN-TH_2P-55935-0210~9u25
CONN-SMD_2P-P1.25-HC-1.25-2PWT~CONN-SMD_2P-P1.25-HC-1.25-2PWT~9u25

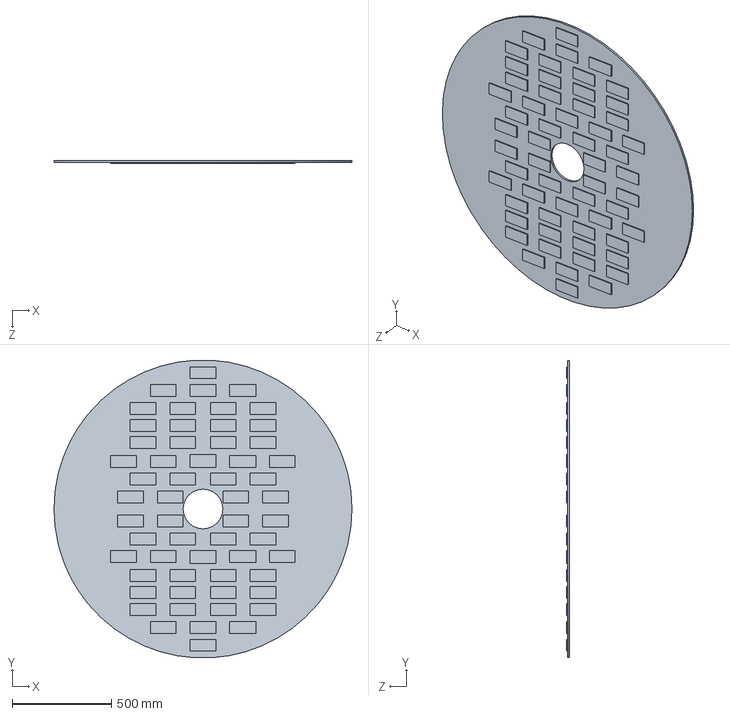
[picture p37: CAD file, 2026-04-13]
just外接板/基板1.SLDPRT
1500.0 x 1497.5 x 15.0 mm

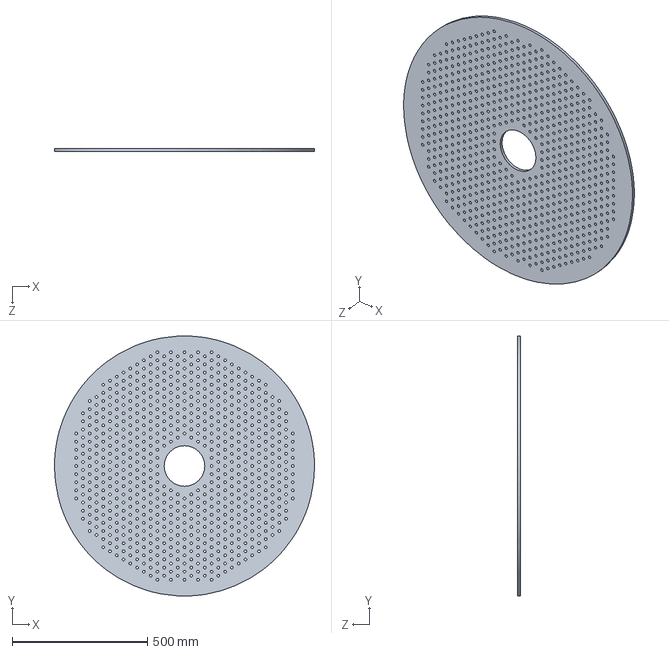
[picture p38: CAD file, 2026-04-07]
just外接板/外接板.SLDPRT
960.0 x 959.7 x 10.0 mm

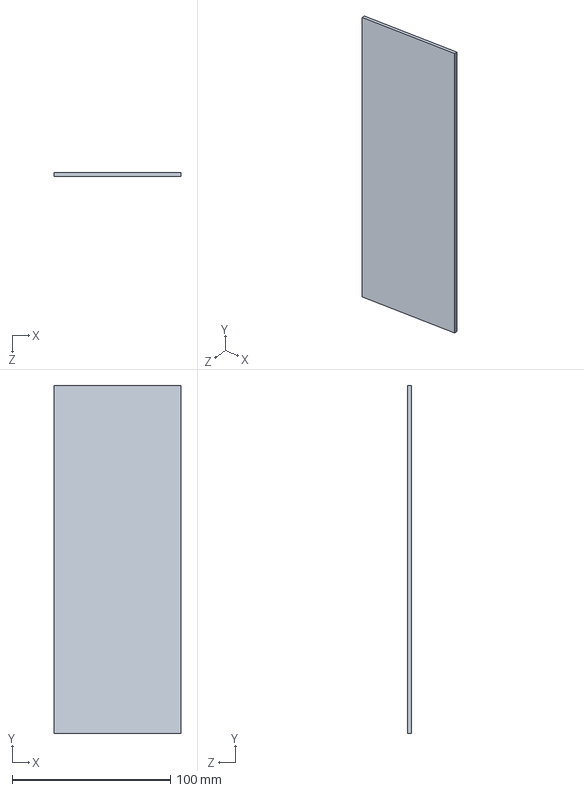
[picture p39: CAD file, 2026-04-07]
just外接板/外接板pcb.SLDPRT
80.0 x 220.0 x 2.50 mm

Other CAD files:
just外接板/布线/各图纸大小图幅框（a0-a4）(1).dwg
just外接板/布线/布线.dwg
just外接板/外接板基板.SLDPRT
just外接板/布线.STL

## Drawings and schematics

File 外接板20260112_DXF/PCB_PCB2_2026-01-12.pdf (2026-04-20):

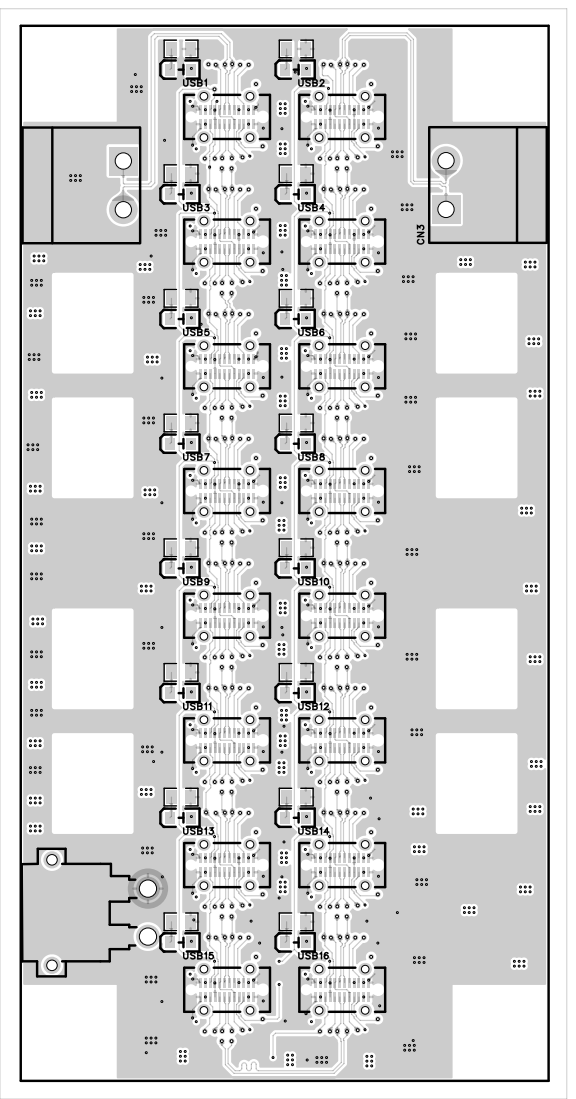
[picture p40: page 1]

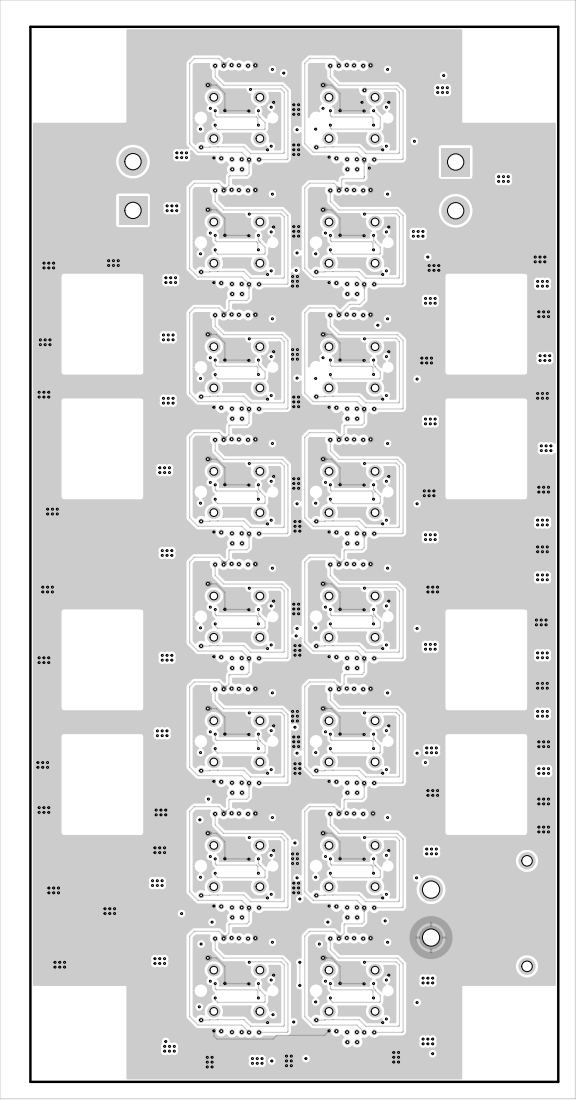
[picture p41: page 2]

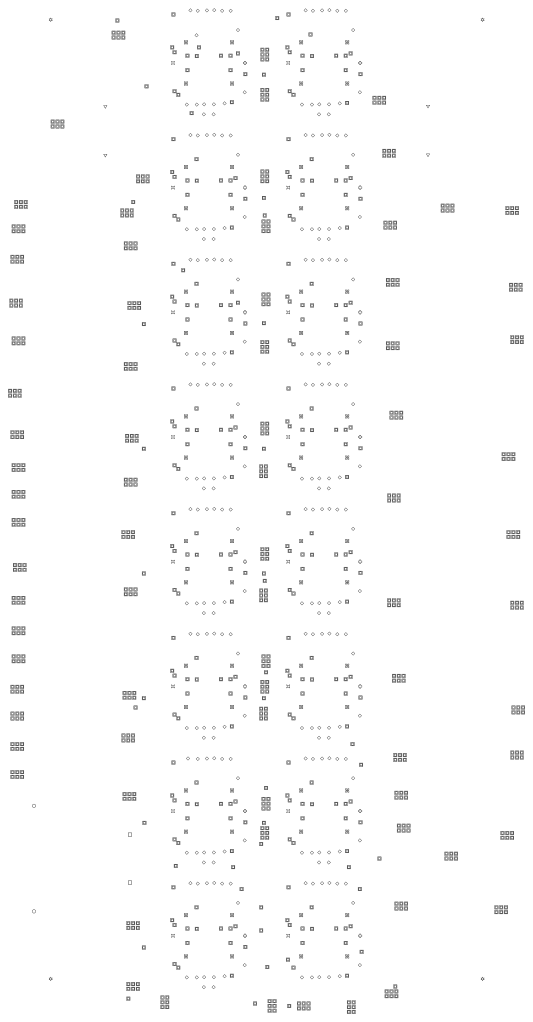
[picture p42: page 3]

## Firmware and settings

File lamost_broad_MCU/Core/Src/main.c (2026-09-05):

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
/* Includes ------------------------------------------------------------------*/
#include "main.h"
#include "can.h"
#include "dma.h"
#include "tim.h"
#include "usart.h"
#include "gpio.h"

/* USER CODE BEGIN Includes */
#include "just_led.h"
#include "stdio.h"
#include "can_rx_buffer.h"
/* USER CODE END Includes */

/* USER CODE BEGIN PD */
extern const uint16_t pcb_map[JUST_BOARD_LED_NUMBER];



/* USER CODE END PD */


/* USER CODE BEGIN PV */

CAN_RX_Handle_t can_rx;


/* USER CODE END PV */

void SystemClock_Config(void);
/**
  * @brief  The application entry point.
  * @retval int
  */
int main(void)
{

  /* MCU Configuration--------------------------------------------------------*/

  /* Reset of all peripherals, Initializes the Flash interface and the Systick. */
  HAL_Init();

  /* Configure the system clock */
  SystemClock_Config();

  /* Initialize all configured peripherals */
  MX_GPIO_Init();
  MX_DMA_Init();
  MX_CAN_Init();
  MX_TIM1_Init();
  MX_USART1_UART_Init();
  /* USER CODE BEGIN 2 */

  HAL_TIM_Base_Start_IT(&htim1); // 启动 TIM1 的基本定时器中断
  HAL_TIM_OC_Start_IT(&htim1,
                      TIM_CHANNEL_1); // 启动 TIM1 的输出比较中断,使用通道 1


  
  CAN_RX_Init(&can_rx, &hcan); // 初始化 CAN 接收环形缓存

  HAL_CAN_Start(&hcan);
  HAL_CAN_ActivateNotification(&hcan, CAN_IT_RX_FIFO0_MSG_PENDING); // 激活 CAN 接收中断，等待接收消息 

   

    for(int j=0;j<JUST_BOARD_LED_NUMBER;j++)
    {
        just_led_control(j, 2); // 设置所有LED为闪烁状态
    }
     just_led_control(10, 1); // 设置所有LED为闪烁状态
  /* USER CODE END 2 */

  /* Infinite loop */
  /* USER CODE BEGIN WHILE */
  while (1) {
   
    /* USER CODE END WHILE */

    /* USER CODE BEGIN 3 */
    CAN_RX_Process(&can_rx);
     


  }
  /* USER CODE END 3 */
}

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
/* USER CODE BEGIN 4 */

// 重定向 printf 到 USART1
int _write(int file, char *ptr, int len) {
  HAL_UART_Transmit(&huart1, (uint8_t *)ptr, len, HAL_MAX_DELAY);
  return len;
}

/* USER CODE END 4 */
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


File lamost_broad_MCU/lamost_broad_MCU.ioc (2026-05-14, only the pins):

Mcu.UserName=STM32F302K8Ux
PA0.Signal=GPIO_Output
PA1.Signal=GPIO_Output
PA10.Signal=USART1_RX
PA11.Signal=CAN_RX
PA12.Signal=CAN_TX
PA13.Signal=SYS_JTMS-SWDIO
PA14.Signal=SYS_JTCK-SWCLK
PA15.Signal=GPIO_Output
PA2.Signal=GPIO_Output
PA3.Signal=GPIO_Output
PA4.Signal=GPIO_Output
PA5.Signal=GPIO_Output
PA6.Signal=GPIO_Output
PA7.Signal=GPIO_Output
PA8.Signal=GPIO_Output
PA9.Signal=USART1_TX
PB0.Signal=GPIO_Output
PB3.Signal=GPIO_Output
PB4.Signal=GPIO_Output
PB5.Signal=GPIO_Output
PB6.Signal=GPIO_Output
PB7.Signal=GPIO_Output
PF0-OSC_IN.Signal=RCC_OSC_IN
PF1-OSC_OUT.Signal=RCC_OSC_OUT

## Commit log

2026-03-17 增大间距
2026-03-17 添加文件
2026-04-02 0402新版外接板，还没设计，距离改为15
2026-04-02 添加soildworks相关文件
2026-04-02 添加了下边的两个孔
2026-04-02 添加3d文件
2026-04-03 电源接口和CAN接口放在背面，增加了挖空区域
2026-04-03 PCB 3D文件
2026-04-03 重新调整布线，can统一放在右侧，
2026-04-03 更换了3DPCB文件
2026-04-07 删除外接板
2026-04-07 添加just外接板，里面有soildwork文件和部分图片以及PPT
    [分块插线板_16.STEP, 分块插线板_16接头间距加大.STEP, 外接板.SLDPRT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]
2026-04-07 添加零件示意图。汇报使用，再加上ps布线
    [外接板基板.SLDPRT, 零件1.SLDPRT]
2026-04-09 添加汇报ppt
2026-04-09 外接板零件图
    [零件1.SLDPRT]
2026-04-13 汇报内容
    [基板1.SLDPRT, 基板2.SLDPRT, 布线.SLDPRT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]
2026-04-13 添加过孔GND调试，添加导电过孔
2026-04-13 添加走线空间图，添加ppt。
    [基板2.SLDPRT, 接口.step]
2026-04-13 修改ppt
2026-04-20 modified: debug.log modified: "just\345\244\226\346\216\245\346\235\277/\345\210\206\345\235\227\346\217\222\347\272\277\346\235\277_16.STEP" modified: "just\345\244\226\346\216\245\346\235\277/\345\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
    [分块插线板_16.STEP, 分块插线板_16接头间距加大.STEP, 外接板基板.STEP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]
2026-04-22 去除多余过孔，为stm32预留空间
2026-04-22 添加ppt
2026-04-22 添加核心板stm32部分原理图
2026-04-23 PCB初定稿
2026-04-24 添加stm32项目工程文件
2026-04-27 更改外接板基板设置，调整大小缩小到1.3米，中间换为方形倒角
    [基板2.SLDPRT]
2026-04-27 调整基板和布线，改为真实情况
    [基板2.SLDPRT, 布线.SLDPRT]
2026-04-28 添加小单元原理图，用于参考电源电路
2026-04-28 删除多余文件
2026-04-28 挖空PCB轮廓1mm
2026-04-28 添加外接板STL通用3D文件
2026-04-30 外接板布局对应PCB初步前端代码
2026-05-03 添加html可视化文件，用于以后可能的对应关系
2026-05-03 改变外接板基板，添加中心对位圆柱孔
2026-05-03 修改CANVAS,已经大致好用，在测试其他功能，比如导出数据的工能还没测试
2026-05-07 添加调试及下载
2026-05-07 GPIO_AF9_CAN引脚复用
2026-05-07 5v->3.3改为功率电感
2026-05-07 main添加打印函数
2026-05-07 添加功率电感，调整CAN收发芯片，连接上3.3v电压
2026-05-07 改为2层板
2026-05-09 两层板打板
2026-05-09 添加测试PCB
2026-05-09 添加LED相关文件
2026-05-09 改变时钟频率
2026-05-09 添加编译文件
2026-05-09 10%占空比亮
2026-05-09 测试just——pcb
2026-05-09 添加任务 ，CMake: 清理重新生成
2026-05-14 添加LED控制代码
2026-05-14 24MHz晶振，CAN中断
2026-05-14 添加CAN测试发送
2026-05-14 添加CAN_HandleTypeDef hcan
2026-05-14 修改定时器，主频现在为72Mhz，can通信为250k
2026-05-14 添加丝印，CANL和CANH标反修正
2026-05-14 添加钽电容
2026-05-14 宏定义位置移动
2026-05-14 添加FIFO 0
2026-05-14 添加Filter，什么也不过滤
2026-05-14 CAN FIFO0中断
2026-05-14 存放中断接收的值
2026-05-14 添加注释
2026-05-14 保存设置
2026-05-15 添加倒角
    [基板2.SLDPRT]
2026-05-25 主节点布局调整
    [基板2.SLDPRT]
2026-06-03 添加末端电阻，添加boot0复位，删除复位按钮， Signed-off-by: dushiyu <820145912@qq.com>
2026-06-03 添加can布线和电源布线
2026-06-10 添加开关控制末端电阻，并添加对应丝印
2026-06-11 添加走线孔，孔直径50mm，中间孔改为150mm直径
    [基板2.SLDPRT]
2026-06-11 绘制CAN总线和电源线。
2026-06-11 添加readme.md
2026-07-09 布线AutoCAD
    [布线.dwg]
2026-07-09 汇报ppt 20260715
2026-08-06 添加布线说明
2026-08-06 添加元器件位号丝印
2026-08-13 更改task.json
2026-08-15 添加TVS、防浪涌
2026-08-20 更改丝印位置
2026-08-20 添加CAN消息接收处理、环形缓冲区
2026-09-04 feat: add three-plane 2D and 3D wiring visualizer
2026-09-04 data: add optimized middle-to-back wiring map
    [optimized_middle_to_back.csv]
2026-09-04 删除多余内容
2026-09-05 保存三层布线最终映射并修复画布显示
    - 固化焦面到理线的726路优化映射
    - 保留并保存理线到铝基板的现有映射结果
    - 修复Canvas映射加载和显示问题
    - 保留优化脚本，便于后续继续调整
    [optimized_middle_to_back.csv]
2026-09-05 清理Canvas无用中间文件
    - 删除旧的局部PCB映射文件
    - 删除由旧映射生成的C数组导出文件
    - 删除可由JSON结果替代的CSV冗余文件
    - 保留当前726路焦面到理线和理线到铝基板的最终布线结果
    [optimized_middle_to_back.csv]
2026-09-05 精简CAN接收缓存并清理调试代码
    - 将CAN接收环形缓存从256帧缩减到32帧
    - 为LED控制接口增加索引范围保护，避免异常命令导致越界
    - 删除主循环中的调试延时和串口打印，仅保留CAN缓冲处理
2026-09-05 补全52块PCB端口映射并支持按板号编译
    - 根据Canvas最终布线结果生成52组PCB端口到外部单元的固定映射
    - 使用PCB_ID条件编译选择当前板映射，未使用端口以0表示
    - 统一使用pcb_map接口并保持USB、LED与数组下标一一对应
2026-09-24 添加网页示意、同时添加程序中的映射
2026-09-24 添加光纤示意图
2026-10-08 备份Canvas现版：保留光纤示意、橙色基准点与420毫米间距
2026-10-08 补充焦面球面坐标与环形基准点参考数据
2026-10-08 新增装配可视化并优化全量光纤绘制
    保留726条映射和26组主节点布局，增加三层装配、基准点与CAN分组查看。合并光纤描边、缓存几何与索引、按帧调度刷新并修正高分屏画布。按实际用途标明外接板静默监听、各主节点下单元ID重复使用1～32，组内板位不作为CAN地址。
2026-10-08 移除旧Canvas入口并同步导出脚本和项目说明
    仅保留canvas_assembly.html，旧版由bb9f067历史提交保留。映射同步脚本迁移到新入口并同步MAIN_GROUPS摘要，临时副本导出验证页面、JSON和固件表逐字节不变。修正文档中的PCB数量、两级CAN职责和静默监听要求，明确MCU实现仍待后续修改。
2026-10-18 添加控制盒原理图、用于对齐typec接口。
2026-10-18 配置外接板CAN静默监听并同步CubeMX工程
    将CAN控制器切换为SILENT模式，并在CubeMX工程中同步Mode参数，保持250kbps位时序。
    验证：当前完整工作区已通过PCB1 Debug与PCB52 Release交叉编译。
    实板接收、ACK和错误标志等电气行为尚未验证。
2026-10-18 新增板号开机显示与CAN亮灯指令处理框架
    支持1至52号PCB编译配置，按十位亮2秒、熄灭1秒、个位亮2秒显示板号，数字0使用LED10。
    接收队列接入非阻塞命令处理，显示期间保存最后一条合法指令；新增目标切换、取消定位和本地诊断状态。
    更新整板LED状态时保护临界区，限制单轮队列处理数量，并检查外设启动结果。
    验证：PCB1 Debug、PCB52 Release编译通过；已有C测试在8组主机配置下通过。
    示例协议默认关闭，端口单元表默认未配置；正式协议、现场接线和实板行为仍待确认。
2026-10-18 添加板号显示与CAN命令主机回归测试
    使用HAL与中断状态替身，覆盖板号显示时间边界、tick回绕、开机缓存指令、非法报文、目标切换和CAN队列回绕。
    验证：直接使用本机GCC，以-Wall -Wextra -Werror编译并运行8组配置，全部通过；覆盖协议关闭、正常映射、ID32、空表、重复及越界单元、PCB10和PCB11。
    文档引用的run_can_command_tests.py当前不在工作区，本次保留原有测试文件，未补充该运行入口。
2026-10-18 修正装配实体视图深度遮挡并支持合成导出
    实体模式使用WebGL2深度检测，批量绘制板面、线路和节点，保留中心孔洞与表面标记。
    按遮挡关系过滤节点拾取和标签，将实体图层合入PNG导出，并在WebGL不可用或上下文丢失时回退到透视查看。
    验证：页面内联JavaScript通过Node语法解析。
    本次未进行浏览器视觉、交互或性能验证。
2026-10-18 补充MCU固件使用说明并更新项目功能文档
    补充板号编译、十进制开机显示、组内单元映射、静默接收、台架示例协议、诊断字段与实板检查方法。
    更新项目总览中的固件状态和装配实体视图深度检测说明，区分全局焦面映射与组内单元编号。
    验证：PCB1 Debug与PCB52 Release编译通过，8组C主机测试通过。
    已知缺项：两份说明引用的tests/run_can_command_tests.py未包含在当前工作区；测试通过直接编译已有C文件完成。正式协议、现场端口表与实板验证仍待补充。
2026-10-18 归档外接板20260402版本776设计备份
    归档2026年10月18日13时42分导出的外接板设计备份，保留原始压缩包。
    已读取ZIP目录，包含原理图、PCB、符号、封装及工程元数据；未对电路或PCB设计作功能审查。
2026-10-19 将热仿真模型改用 Git LFS 存储
2026-10-19 优化布线、第一个口下载调试程序、结合热仿真、优化PCB。
2026-10-19 支持2D截面布线视图并更新装配说明文档

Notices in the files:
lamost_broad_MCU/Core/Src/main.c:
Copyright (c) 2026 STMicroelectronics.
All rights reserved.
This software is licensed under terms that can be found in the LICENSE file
